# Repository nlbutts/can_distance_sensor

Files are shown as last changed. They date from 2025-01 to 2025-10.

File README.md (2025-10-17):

# I'm Not Touching You

This is a small CAN based Time-of-Flight (TOF) sensor. It determines the distance
to an object and sends the resulting message on the CAN bus.

# Design
The block diagram is shown below. The design consists of an input buck regulator.
The regulator should be good up to 24V, but was designed to work at 12V. There
is reverse battery protection, so it should handle accidentially connecting
the battery up in reverse.

The buck generates 5V which is used for the CAN transceiver. The 5V is fed
to two LDO's to generate 3.3V for the processor and 2.8V for the TOF sensor.

There are two status LEDs on the board. An STM32G431 processor powers everything.

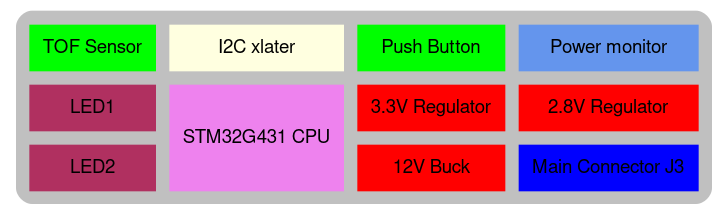
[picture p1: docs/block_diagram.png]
block diagram


There are three user accessible connectors:
Main J3:
| Pin | Use |
| -- | -- |
| 1 | Power |
| 2 | Ground |
| 3 | CAN High |
| 4 | CAN Low |

The mate is a **JST PHR-4**

There is a standard USB Micro B connector that connects to a PC. It enumerates
as a serial port.

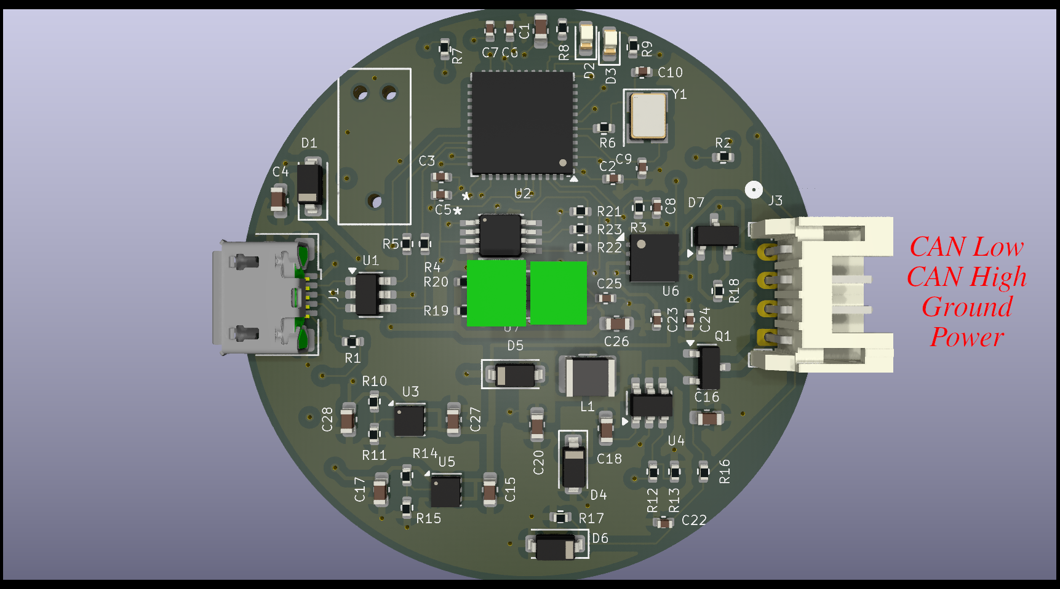
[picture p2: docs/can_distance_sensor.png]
pinout1


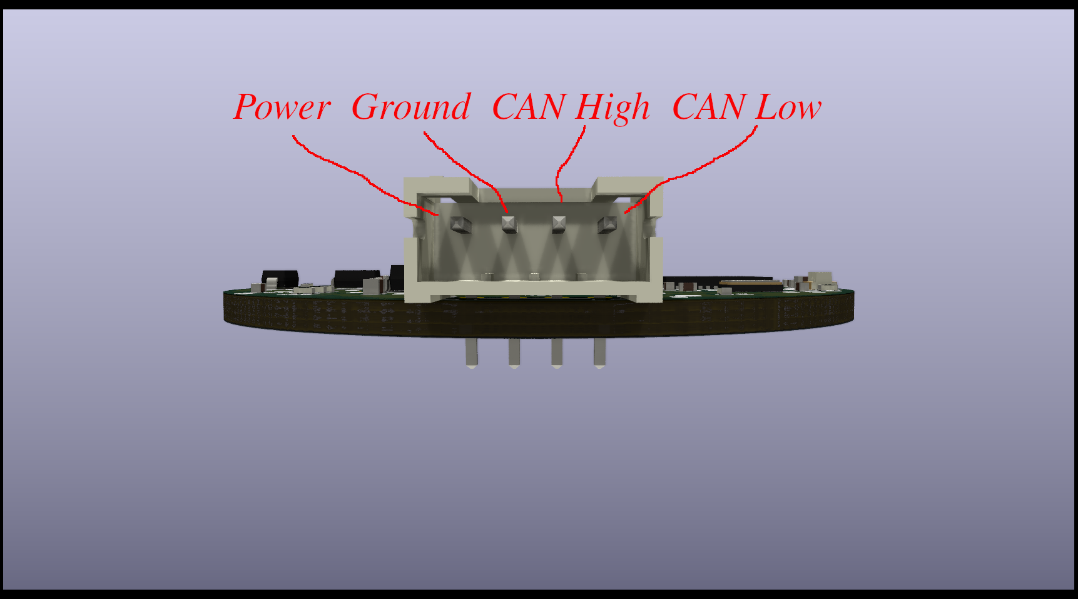
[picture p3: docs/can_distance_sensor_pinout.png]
pinout2


# Software
The software uses the STM32CubeIDE to build the code. I really wanted to use CMake with the CubeMX tool,
but I was having trouble getting the code to work correctly. So CudeIDE for the win.

The code is SUPER simple. It just reads the TOF sensor once every 100 ms and sends out a CAN message.

The CAN message is defined as:
| Byte | Definition |
| ---- | --- |
| 1 | API Status |
| 2-3 | distance in mm |
| 4-5 | ambient Mcps |
| 6-7 | signal Mcps |

The **API Status** is the not well defined. If the value is zero, the distance is valid.
The distance is in millimeters.
The Ambient and Signal values are in Millions of Chips Per Second.

The CAN ID is based on the WPILib CAN interface:

CANID

Device Type is Misc (10)
Manufacturer is 20
API Class is Status (5)
API Index is 0
Device Number is currently 0 (need to figure out how to have several of these on the bus)

## SWD Debug
It is assumed you are using a JLink and it is installed in **/opt/SEGGER/JLink**
In the scripts directory:
1) Run **gdbstart.sh** in one terminal
2) Run debug.sh in other terminal. You now have the full power of GDB at your literial finger tips

## Firmware upgrade
There is no ability to upgrade the firmware right now. It will be fixed in future PCB rev.
Currently you have to JTAG/SWD the firmware.

# Potential other parts
STM32G0:
https://jlcpcb.com/partdetail/STMicroelectronics-STM32G0B1CBT6/C2847904
Can we use a M0???

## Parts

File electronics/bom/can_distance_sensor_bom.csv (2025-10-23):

Designator | Footprint | JLCPCB | Description
C1,C15,C17,C26,C27,C28 | Capacitor_SMD:C_0603_1608Metric | C19666
C2,C3,C8,C23,C24,C25 | Capacitor_SMD:C_0402_1005Metric | C1525
C4 | Capacitor_SMD:C_0603_1608Metric | C23630
C9,C10 | Capacitor_SMD:C_0402_1005Metric | C1548
C16,C20 | Capacitor_SMD:C_0603_1608Metric | C96446
C22 | Capacitor_SMD:C_0402_1005Metric | C52923
D1,D5 | Diode_SMD:D_SOD-123 | C8598
D2,D3 | LED_SMD:LED_0603_1608Metric | C2286
D6 | Diode_SMD:D_SOD-123 | C2105 | Zener diode
D7,D8,D9 | Package_TO_SOT_SMD:SOT-23 | C32677
J3 | Connector_JST:JST_PH_S4B-PH-K_1x04_P2.00mm_Horizontal | C160354 | Generic connector, single row, 01x04, script generated (kicad-library-utils/schlib/autogen/connector/)
J4 | Connector_JST:JST_PH_S6B-PH-K_1x06_P2.00mm_Horizontal | C157920 | Generic connector, single row, 01x06, script generated (kicad-library-utils/schlib/autogen/connector/)
J5 | footprints:CONN_105450-0101_MOL | C134092 | USB Full-Featured Type-C Receptacle connector
Q2 | Package_TO_SOT_SMD:SOT-23 | C15127 | -4.0A Id, -30V Vds, P-Channel MOSFET, SOT-23
R2,R6 | Resistor_SMD:R_0402_1005Metric | C11702
R3,R16 | Resistor_SMD:R_0402_1005Metric | C25741
R4,R5 | Resistor_SMD:R_0402_1005Metric | C25092
R7 | Resistor_SMD:R_0402_1005Metric | C25900
R8,R9 | Resistor_SMD:R_0402_1005Metric | C25104
R17 | Resistor_SMD:R_0402_1005Metric | C25744
R18 | Resistor_SMD:R_0402_1005Metric | C25079
R19,R20,R22 | Resistor_SMD:R_0402_1005Metric | C25744
R21,R23 | Resistor_SMD:R_0402_1005Metric | C25879
SW1 | footprints:PTS645SK50SMTR92LFS_CNK | C221872
U1 | Package_TO_SOT_SMD:SOT-23-6 | C7519 | Very low capacitance ESD protection diode, 2 data-line, SOT-23-6
U2 | footprints:VREG_L78M05ABDT-TR | C58069
U3 | Package_TO_SOT_SMD:SOT-23 | C14255 | Torex XC6206P282MR-G 200-mA Ultra-Low-Iq LDO, 0.8V, SOT-23-3
U4 | Package_TO_SOT_SMD:SOT-23 | C5446 | Torex XC6206P332MR-G 200-mA Ultra-Low-Iq LDO, 0.8V, SOT-23-3
U6 | Package_SON:VSON-8-1EP_3x3mm_P0.65mm_EP1.6x2.4mm | C3234119 | High-speed CAN-FD Transceiver
U7 | footprints:LGA12_STM | C3178291
U8 | footprints:DGK8 | C478462
U9 | Package_DFN_QFN:QFN-32-1EP_5x5mm_P0.5mm_EP3.45x3.45mm | C5159549 | STMicroelectronics Arm Cortex-M0+ MCU, 128KB flash, 144KB RAM, 64 MHz, 1.7-3.6V, 30 GPIO, UFQFPN32
Y1 | Crystal:Crystal_SMD_3225-4Pin_3.2x2.5mm | C156247 | Four pin crystal, GND on pins 2 and 4

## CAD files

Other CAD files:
mechanical/TCA9509DGKR.step
mechanical/VL53L3CXV0DH_1.step
mechanical/PTS645SK50SMTR92LFS.step
mechanical/en12-hs22af20.stp
mechanical/c-282834-3-c-3d.stp
mechanical/can_distance_sensor.step
mechanical/QFN28_6X6MC_MCH.step
mechanical/10118193-0001lfc.stp
mechanical/1054500101.stp

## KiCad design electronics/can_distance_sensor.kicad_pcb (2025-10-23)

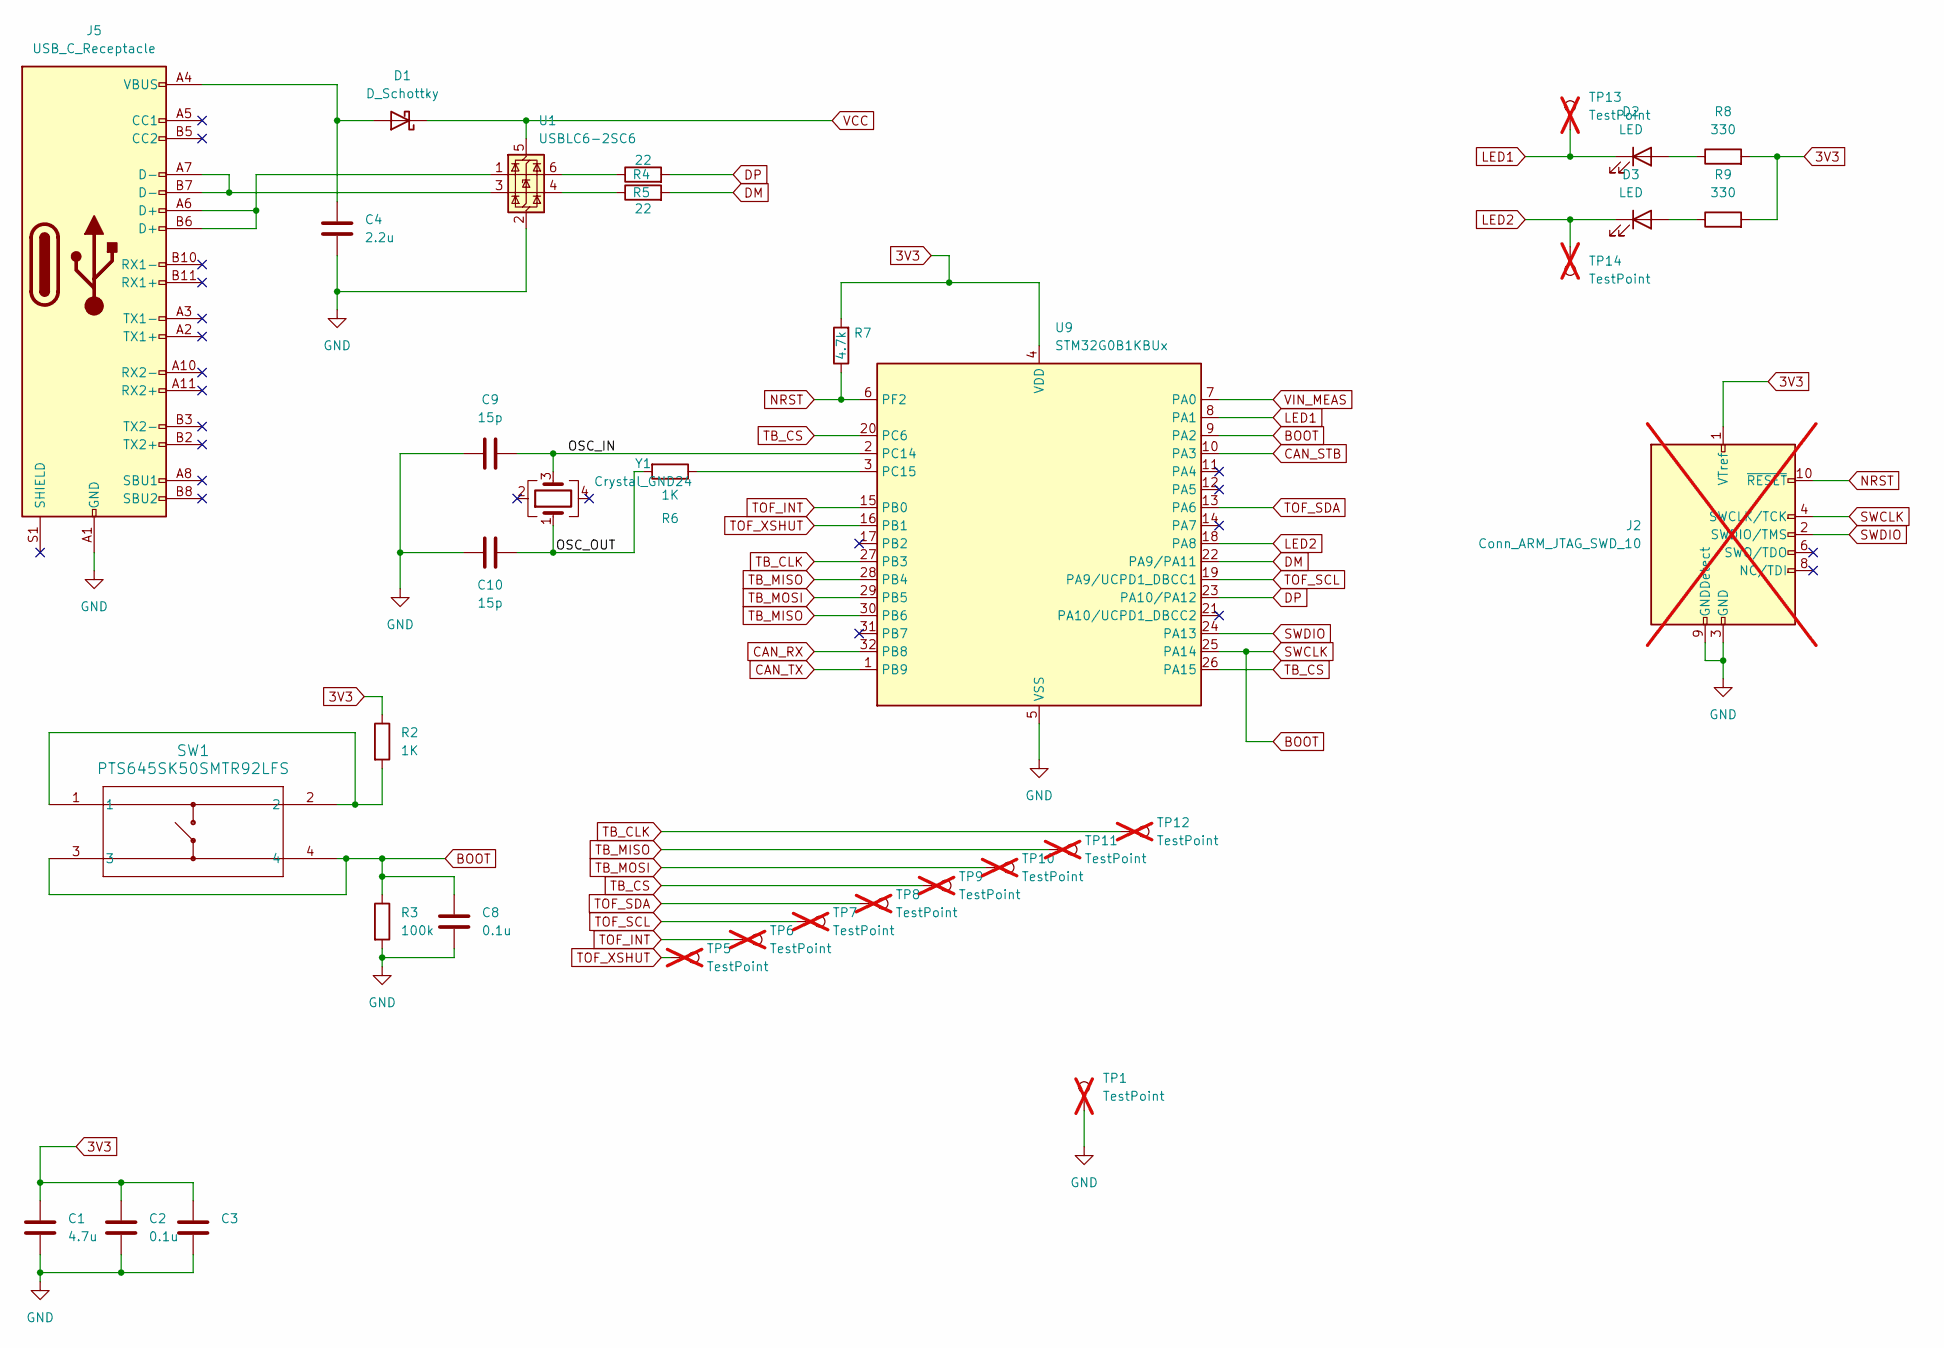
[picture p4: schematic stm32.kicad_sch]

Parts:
C1: 4.7u; C_0603_1608Metric; JLCPCB C19666
C2, C3, C8: 0.1u; C_0402_1005Metric; JLCPCB C1525
C4: 2.2u; C_0603_1608Metric; JLCPCB C23630
C9, C10: 15p; C_0402_1005Metric; JLCPCB C1548
D1: D_Schottky; D_SOD-123; Digikey B0540W-FDICT-ND
D2, D3: LED; LED_0603_1608Metric; JLCPCB C2286
J2: Conn_ARM_JTAG_SWD_10; Tag-Connect_TC2050-IDC-NL_2x05_P1.27mm_Vertical_with_bottom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; not fitted
J5: USB_C_Receptacle; CONN_105450-0101_MOL; JLCPCB C134092
R2, R6: 1K; R_0402_1005Metric; JLCPCB C11702
R3: 100k; R_0402_1005Metric; JLCPCB C25741
R4, R5: 22; R_0402_1005Metric; JLCPCB C25092
R7: 4.7k; R_0402_1005Metric; JLCPCB C25900
R8, R9: 330; R_0402_1005Metric; JLCPCB C25104
SW1: PTS645SK50SMTR92LFS; PTS645SK50SMTR92LFS_CNK; JLCPCB C221872
TP1, TP5, TP6, TP7, TP8, TP9, TP10, TP11, TP12, TP13, TP14: TestPoint; TestPoint_Pad_D1.0mm; not fitted
U1: USBLC6-2SC6; SOT-23-6; JLCPCB C7519
U9: STM32G0B1KBUx; QFN-32-1EP_5x5mm_P0.5mm_EP3.45x3.45mm; JLCPCB C5159549
Y1: Crystal_GND24; Crystal_SMD_3225-4Pin_3.2x2.5mm; JLCPCB C156247

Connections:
3V3: C1.1, C2.1, C3.1, J2.1 (VTref), R2.1, R7.2, R8.2, R9.2, U9.4 (VDD); also elsewhere on the board
/STM32/OSC_IN: C9.2, U9.2 (PC14), Y1.3
/STM32/OSC_OUT: C10.2, R6.2, Y1.1
BOOT: C8.1, J2.4 (SWCLK/TCK), R3.1, SW1.3, SW1.4, U9.9 (PA2), U9.25 (PA14)
CAN_RX: U9.32 (PB8); also elsewhere on the board
CAN_STB: U9.10 (PA3); also elsewhere on the board
CAN_TX: U9.1 (PB9); also elsewhere on the board
DM: R5.2, U9.22 (PA9/PA11)
DP: R4.2, U9.23 (PA10/PA12)
GND: C1.2, C2.2, C3.2, C4.1, C8.2, C9.1, C10.1, J2.3 (GND), J2.5 (GND), J2.9 (GNDDetect), J5.A1 (GND), J5.A12 (GND), J5.B1 (GND), J5.B12 (GND), R3.2, TP1.1, U1.2 (GND), U9.5 (VSS), U9.33 (VSS); also elsewhere on the board
LED1: D2.1 (K), TP13.1, U9.8 (PA1)
LED2: D3.1 (K), TP14.1, U9.18 (PA8)
NRST: J2.10 (~RESET), R7.1, U9.6 (PF2)
unnamed: C4.2, D1.2 (A), J5.A4 (VBUS), J5.A9 (VBUS), J5.B4 (VBUS), J5.B9 (VBUS)
unnamed: D2.2 (A), R8.1
unnamed: D3.2 (A), R9.1
unnamed: J5.A6 (D+), J5.B6 (D+), U1.1 (I/O1)
unnamed: J5.A7 (D-), J5.B7 (D-), U1.3 (I/O2)
unnamed: R2.2, SW1.1, SW1.2
unnamed: R4.1, U1.6 (I/O1)
unnamed: R5.1, U1.4 (I/O2)
unnamed: R6.1, U9.3 (PC15)
SWDIO: J2.2 (SWDIO/TMS), U9.24 (PA13)
TB_ABS: TP11.1, U9.28 (PB4), U9.30 (PB6); also elsewhere on the board
TB_CLK: TP12.1, U9.27 (PB3); also elsewhere on the board
TB_CS: TP9.1, U9.20 (PC6), U9.26 (PA15); also elsewhere on the board
TB_MOSI: TP10.1, U9.29 (PB5); also elsewhere on the board
TOF_INT: TP6.1, U9.15 (PB0); also elsewhere on the board
TOF_SCL: TP7.1, U9.19 (PA9/UCPD1_DBCC1); also elsewhere on the board
TOF_SDA: TP8.1, U9.13 (PA6); also elsewhere on the board
TOF_XSHUT: TP5.1, U9.16 (PB1); also elsewhere on the board
VCC: D1.1 (K), U1.5 (VBUS); also elsewhere on the board
VIN_MEAS: U9.7 (PA0); also elsewhere on the board

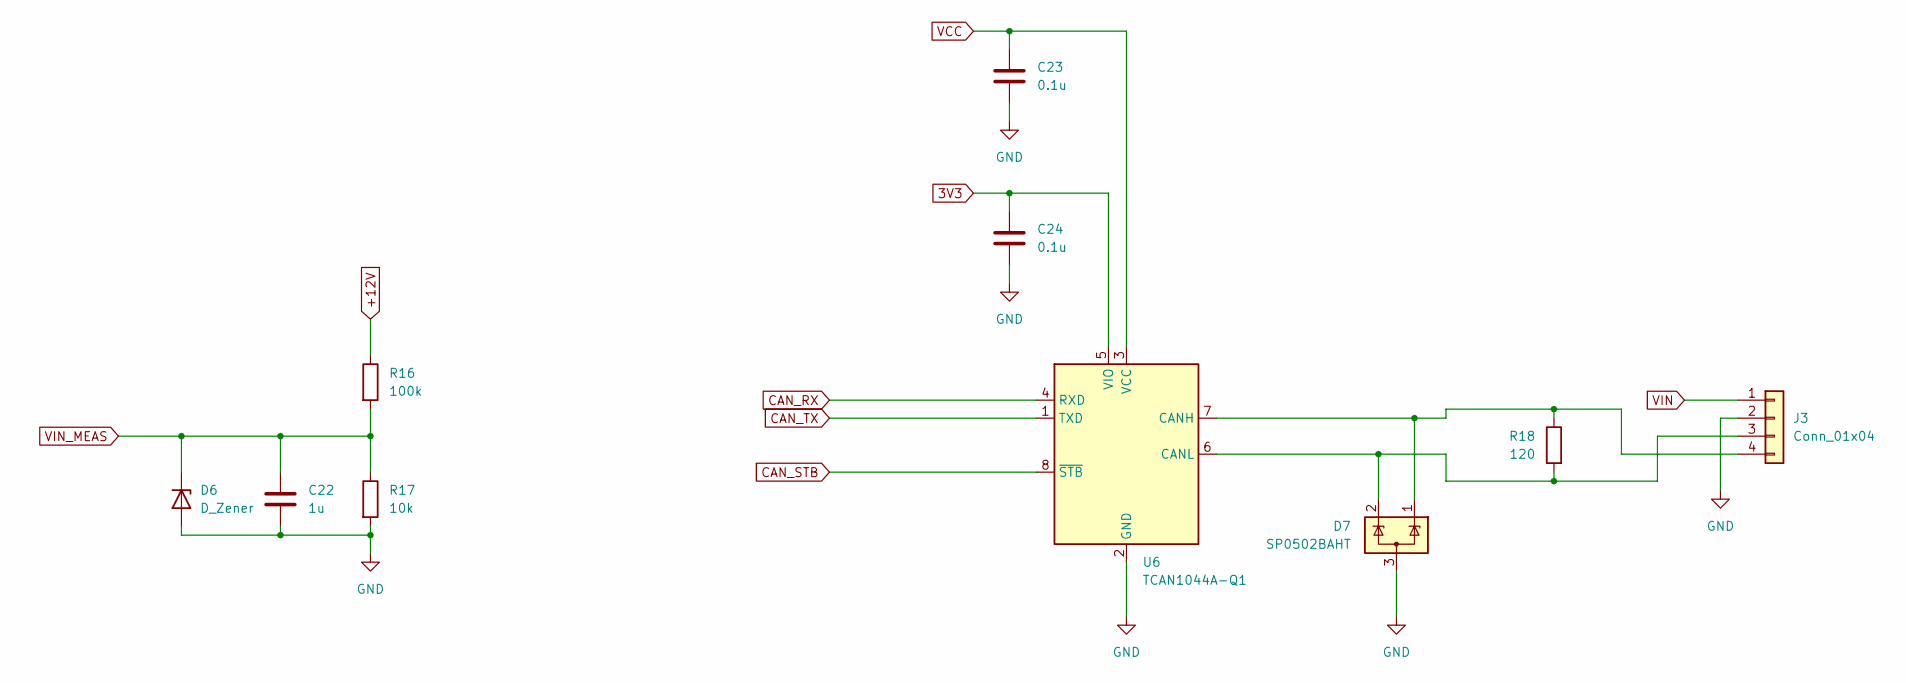
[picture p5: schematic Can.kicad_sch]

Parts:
C22: 1u; C_0402_1005Metric; JLCPCB C52923
C23, C24: 0.1u; C_0402_1005Metric; JLCPCB C1525
D6: D_Zener; D_SOD-123; JLCPCB C2105
D7: SP0502BAHT; SOT-23; JLCPCB C32677
J3: Conn_01x04; JST_PH_S4B-PH-K_1x04_P2.00mm_Horizontal; JLCPCB C160354
R16: 100k; R_0402_1005Metric; JLCPCB C25741
R17: 10k; R_0402_1005Metric; JLCPCB C25744
R18: 120; R_0402_1005Metric; JLCPCB C25079
U6: TCAN1044A-Q1; VSON-8-1EP_3x3mm_P0.65mm_EP1.6x2.4mm; JLCPCB C3234119

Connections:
3V3: C24.1, U6.5 (VIO); also elsewhere on the board
+12V: R16.1; also elsewhere on the board
CAN_RX: U6.4 (RXD); also elsewhere on the board
CAN_STB: U6.8 (~STB); also elsewhere on the board
CAN_TX: U6.1 (TXD); also elsewhere on the board
GND: C22.2, C23.2, C24.2, D6.2 (A), D7.3 (A), J3.2, R17.2, U6.2 (GND); also elsewhere on the board
unnamed: D7.2 (K), J3.3, R18.2, U6.6 (CANL)
unnamed: D7.1 (K), J3.4, R18.1, U6.7 (CANH)
VCC: C23.1, U6.3 (VCC); also elsewhere on the board
VIN: J3.1; also elsewhere on the board
VIN_MEAS: C22.1, D6.1 (K), R16.2, R17.1; also elsewhere on the board

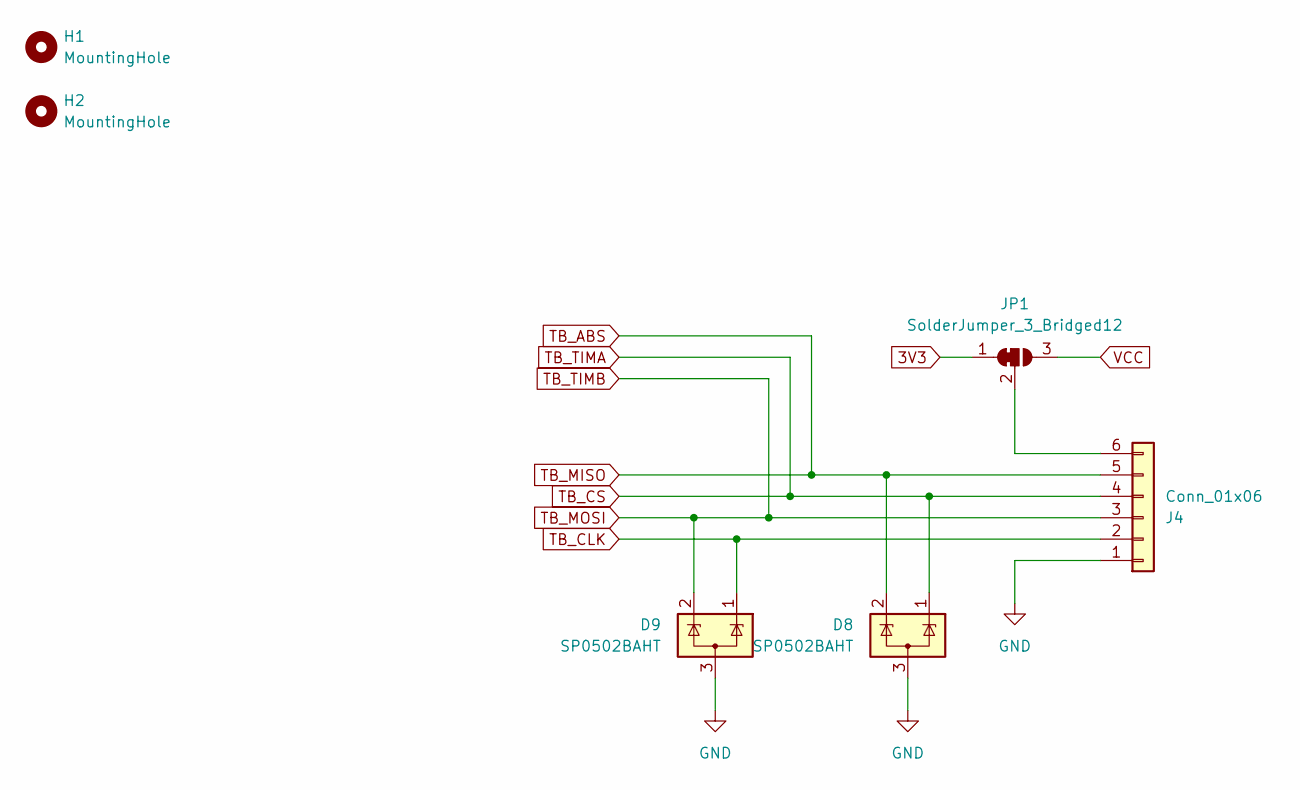
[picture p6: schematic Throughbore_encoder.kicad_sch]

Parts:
D8, D9: SP0502BAHT; SOT-23; JLCPCB C32677
H1, H2: MountingHole; MountingHole_2.2mm_M2
J4: Conn_01x06; JST_PH_S6B-PH-K_1x06_P2.00mm_Horizontal; JLCPCB C157920
JP1: SolderJumper_3_Bridged12; SolderJumper-3_P1.3mm_Bridged2Bar12_RoundedPad1.0x1.5mm_Num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

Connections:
3V3: JP1.1 (A); also elsewhere on the board
GND: D8.3 (A), D9.3 (A), J4.1; also elsewhere on the board
unnamed: J4.6, JP1.2 (C)
TB_ABS: D8.2 (K), J4.5; also elsewhere on the board
TB_CLK: D9.1 (K), J4.2; also elsewhere on the board
TB_CS: D8.1 (K), J4.4; also elsewhere on the board
TB_MOSI: D9.2 (K), J4.3; also elsewhere on the board
VCC: JP1.3 (B); also elsewhere on the board

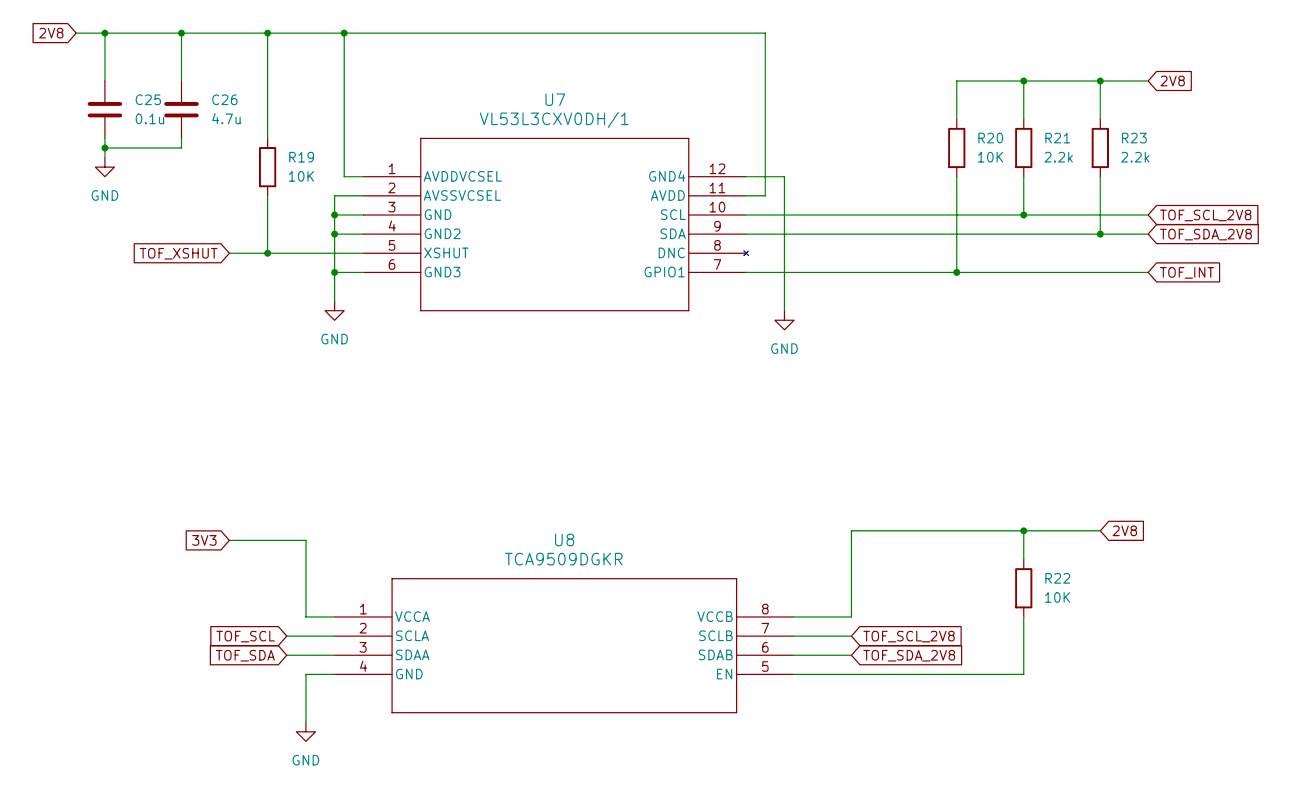
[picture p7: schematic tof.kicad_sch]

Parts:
C25: 0.1u; C_0402_1005Metric; JLCPCB C1525
C26: 4.7u; C_0603_1608Metric; JLCPCB C19666
R19, R20, R22: 10K; R_0402_1005Metric; JLCPCB C25744
R21, R23: 2.2k; R_0402_1005Metric; JLCPCB C25879
U7: VL53L3CXV0DH/1; LGA12_STM; JLCPCB C3178291
U8: TCA9509DGKR; DGK8; JLCPCB C478462

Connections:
2V8: C25.1, C26.1, R19.1, R20.1, R21.1, R22.1, R23.1, U7.1 (AVDDVCSEL), U7.11 (AVDD), U8.8 (VCCB); also elsewhere on the board
3V3: U8.1 (VCCA); also elsewhere on the board
GND: C25.2, C26.2, U7.2 (AVSSVCSEL), U7.3 (GND), U7.4 (GND2), U7.6 (GND3), U7.12 (GND4), U8.4 (GND); also elsewhere on the board
unnamed: R22.2, U8.5 (EN)
TOF_INT: R20.2, U7.7 (GPIO1); also elsewhere on the board
TOF_SCL: U8.2 (SCLA); also elsewhere on the board
TOF_SCL_2V8: R21.2, U7.10 (SCL), U8.7 (SCLB)
TOF_SDA: U8.3 (SDAA); also elsewhere on the board
TOF_SDA_2V8: R23.2, U7.9 (SDA), U8.6 (SDAB)
TOF_XSHUT: R19.2, U7.5 (XSHUT); also elsewhere on the board

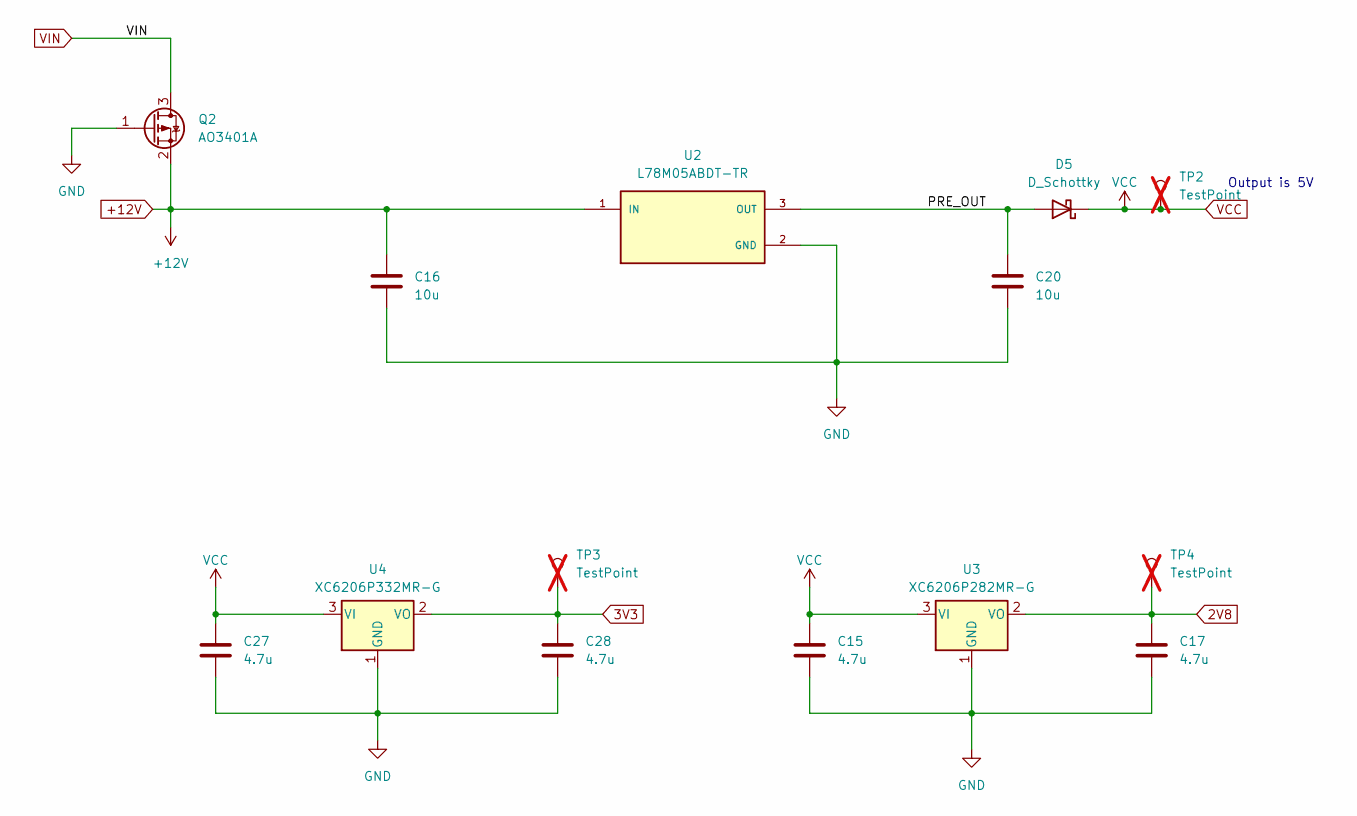
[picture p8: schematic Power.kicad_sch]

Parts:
C15, C17, C27, C28: 4.7u; C_0603_1608Metric; JLCPCB C19666
C16, C20: 10u; C_0603_1608Metric; Digikey 490-5523-1-ND
D5: D_Schottky; D_SOD-123; Digikey B0540W-FDICT-ND
Q2: AO3401A; SOT-23; JLCPCB C15127
TP2, TP3, TP4: TestPoint; TestPoint_Pad_D1.0mm; not fitted
U2: L78M05ABDT-TR; VREG_L78M05ABDT-TR; PARTREV 23; JLCPCB C58069
U3: XC6206P282MR-G; SOT-23; JLCPCB C14255
U4: XC6206P332MR-G; SOT-23; JLCPCB C5446

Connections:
2V8: C17.1, TP4.1, U3.2 (VO); also elsewhere on the board
3V3: C28.1, TP3.1, U4.2 (VO); also elsewhere on the board
+12V: C16.1, Q2.2 (S), U2.1 (IN); also elsewhere on the board
/Power/PRE_OUT: C20.1, D5.2 (A), U2.3 (OUT)
GND: C15.2, C16.2, C17.2, C20.2, C27.2, C28.2, Q2.1 (G), U2.2 (GND), U3.1 (GND), U4.1 (GND); also elsewhere on the board
VCC: C15.1, C27.1, D5.1 (K), TP2.1, U3.3 (VI), U4.3 (VI); also elsewhere on the board
VIN: Q2.3 (D); also elsewhere on the board

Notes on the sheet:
Output is 5V

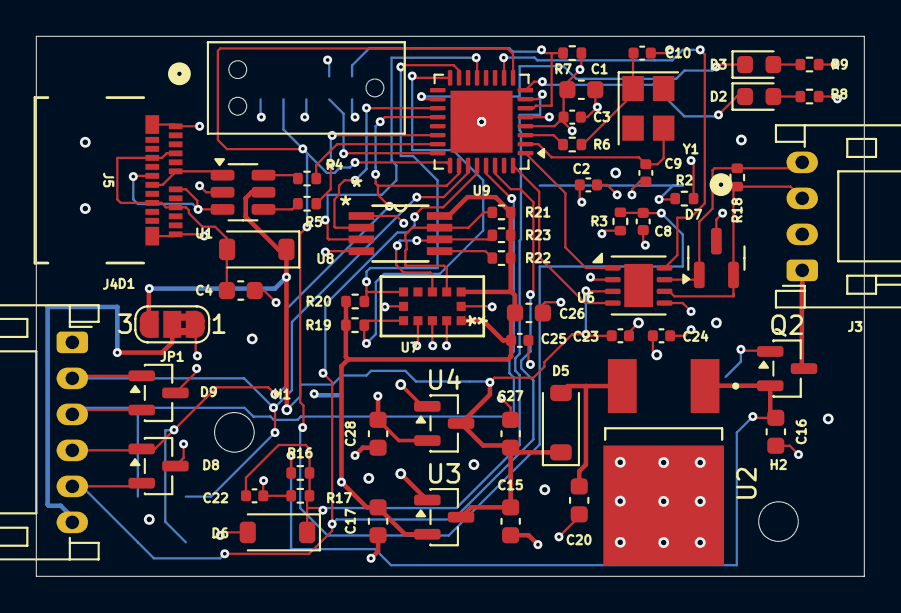
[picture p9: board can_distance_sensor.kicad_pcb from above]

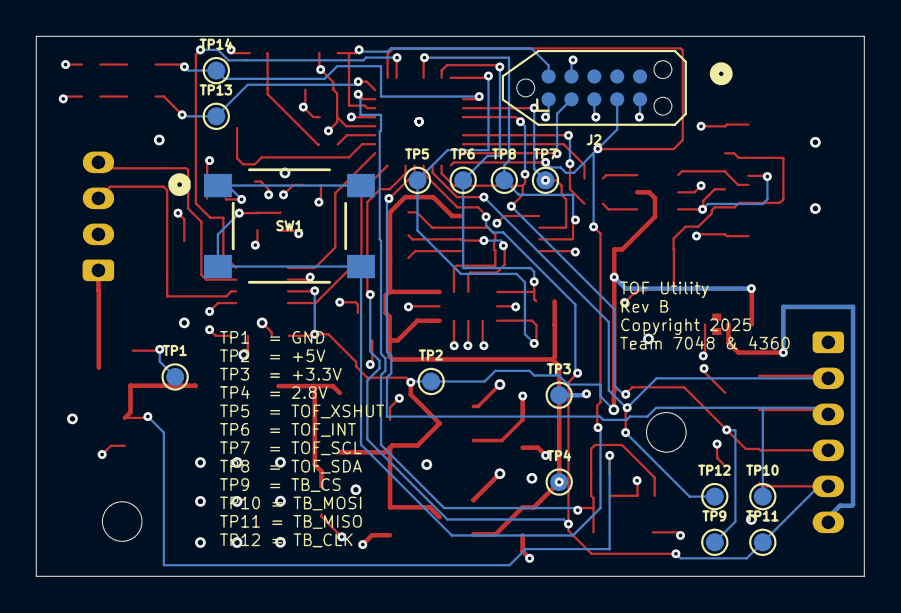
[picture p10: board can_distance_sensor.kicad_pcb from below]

Board: 4 copper layers, 46.0 x 30.0 mm, 74 parts (16 on the bottom side), 43 nets.

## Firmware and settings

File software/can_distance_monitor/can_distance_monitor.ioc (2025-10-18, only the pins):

Mcu.UserName=STM32G0B1KBUx
PA0.Signal=ADC1_IN0
PA1.GPIO_Label=LED1
PA1.Signal=GPIO_Output
PA13.Signal=SYS_SWDIO
PA14-BOOT0.Signal=SYS_SWCLK
PA15.Signal=SPI1_NSS
PA3.GPIO_Label=CAN_STB
PA3.Signal=GPIO_Output
PA4.Signal=USART6_TX
PA5.Signal=USART6_RX
PA6.Signal=I2C2_SDA
PA8.GPIO_Label=LED2
PA8.Signal=GPIO_Output
PA9.Signal=I2C2_SCL
PB0.GPIO_Label=TOF_INT
PB0.Signal=GPIO_Input
PB1.GPIO_Label=TOF_XSHUT
PB1.Signal=GPIO_Output
PB3.Signal=SPI1_SCK
PB4.Signal=SPI1_MISO
PB5.Signal=SPI1_MOSI
PB6.Signal=S_TIM4_CH1
PB8.Signal=FDCAN1_RX
PB9.Signal=FDCAN1_TX
PC6.Signal=S_TIM3_CH1

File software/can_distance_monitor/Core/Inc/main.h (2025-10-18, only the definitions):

#define LED1_Pin GPIO_PIN_1
#define LED1_GPIO_Port GPIOA
#define CAN_STB_Pin GPIO_PIN_3
#define CAN_STB_GPIO_Port GPIOA
#define TOF_INT_Pin GPIO_PIN_0
#define TOF_INT_GPIO_Port GPIOB
#define TOF_XSHUT_Pin GPIO_PIN_1
#define TOF_XSHUT_GPIO_Port GPIOB
#define LED2_Pin GPIO_PIN_8
#define LED2_GPIO_Port GPIOA

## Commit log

2024-11-24 Initial checkin.
    [Can.kicad_sch, IO.kicad_sch, PTS645SK50SMTR92LFS.step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]
2024-11-24 Switched to a lower cost TOF sensor.
    [can_distance_sensor-B_Mask.gbr, can_distance_sensor-B_Paste.gbr, can_distance_sensor-B_Silkscreen.gbr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]
2024-11-29 Ordered this version.
    [Can.kicad_sch, Power.kicad_sch, VL53L0X.step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]
2025-01-01 Commiting the STM32CudeIDE Software.
    [PTS645SK50SMTR92LFS.step, QFN28_6X6MC_MCH.step, VL53L0X.step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]
2025-10-13 Pulled in the latest ST code. Started work on next rev.
    [Can.kicad_sch, PTS645SK50SMTR92LFS.step, Power.kicad_sch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]
2025-10-17 Added a stat printing task.
2025-10-18 Major refactor to rev B
    [Can.kicad_sch, PTS645SK50SMTR92LFS.step, Power.kicad_sch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]
2025-10-18 Checked in more files.
    [10118193-0001lfc.stp, 1054500101.stp, TCA9509DGKR.step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]
2025-10-18 Was going to order this, but 5 boards is 50.
    [can_distance_sensor-top-pos_jlcpcb.csv, can_distance_sensor_bom.csv, can_distance_sensor_bom_jlcpcb.csv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]
2025-10-20 Added the BOM
    [can_distance_sensor-top.csv, can_distance_sensor_bom_jlcpcb.csv]
2025-10-23 Refactored the design to use basic parts.
    [Can.kicad_sch, Power.kicad_sch, QFN28_6X6MC_MCH.step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]
2025-10-23 This part was ordered
    [can_distance_sensor-top-pos_jlcpcb.csv]

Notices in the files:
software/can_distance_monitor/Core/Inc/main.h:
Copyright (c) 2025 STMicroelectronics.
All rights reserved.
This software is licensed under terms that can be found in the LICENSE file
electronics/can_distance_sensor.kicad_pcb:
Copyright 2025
